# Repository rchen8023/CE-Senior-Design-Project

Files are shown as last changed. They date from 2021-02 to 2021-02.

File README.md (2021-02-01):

# CE-Senior-Design-Project

This project aims to create and design an independent IoT system allowing users to open and close their household vertical blinds with just a simple tap on their personal mobile phones or tablets. The project requires three parts involving the software, hardware, and mechanical developments. The software aspect involves a web application which allows the user to open or close the blinds as they wish. The web application communicates to the hardware unit via WiFi where the user data is received by the System On Chip (SoC), ESP8266. The ESP8266 can then send out PWM signals to the stepper motor which along with the mechanical design is able to physically move the window blinds. The web application is implemented using HTML and CSS styling uploaded to the ESP8266 web server. The ESP8266 is programmed using the Arduino IDE, and the mechanical design independently sketched and designed using Tinkercad

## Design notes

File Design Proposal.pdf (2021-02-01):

December 17, 2018

Smart Window Blinds
Aya Mistica & Rui Chen
Design Proposal

Aya Mistica & Rui Chen
1000 E University Ave
Laramie, WY 82071
amistic1@uwyo.edu | rchen2@uwyo.edu

December 6, 2018

Dr. Steven F. Barrett, Professor
University of Wyoming
College of Engineering and Applied Science 1000 E University Ave (EN 2085B) Laramie, WY 82071

Dear Dr. Barrett:

We, Aya Mistica and Rui Chen, both 4th year computer engineering students, are pleased to commence our senior design project for EE 4820. We would like to propose a project to create and design smart window blinds. This project features both software and hardware implementations, but we are excited to take on a project which will challenge our technical skills and knowledge to further mold us into competent and knowledgeable computer engineers. This cover letter will provide an overview of our proposed idea.

According to a survey conducted by Pew Research Center in January 2018, over 77% of American adults own or use a smartphone [1]. Due to the growth in smartphone users, wireless technologies have become more and more integrated into everyday objects and given rise to the Internet of Things (IoT). By 2025, it is estimated that there will be more than 55 billion IoT devices [2]. For these reasons, we propose to create and design wirelessly-controlled window blinds which will allow users to install the mechanism on pre-existing window blinds and control the blinds from their smartphone. Through the mobile app, users should be able to open, close, raise and lower the window blinds. This project aims to design an independent system allowing users to fully utilize their household blinds with just a tap on their screen.

We feel that this project will not only challenge us both technically and creatively, but will help us gain knowledge and understanding within the growing IoT field. Feel free to contact us with feedback and concerns through our school emails: amistic1@uwyo.edu or rchen2@uwyo.edu. We sincerely appreciate your time.

Kind regards,

Aya Mistica and Rui Chen

The Smart Window Blinds project aims to create a self-contained system which will

allow users to fully automate window blinds through their smartphone. The system consists of

two main components: an attachable module that provides motorized control to open, close, raise

and lower the window blinds and a smartphone app which will connect to the attachable module

over Wifi. For design and implementation purposes, the project is divided into three technical

aspects: software, hardware, and mechanical.

The objective of the software portion of the project is to create a mobile application

through Evothings Studio which will allow the user to communicate to our chosen

microcontroller, the ESP8266. Another goal for the smartphone app is to implement a

straightforward, clean interface for an easy-to-use experience. We would also like to add security

measures between the IoT device and mobile app to protect the privacy and data of our users.

On the hardware side, we will be using the ESP 8266 as the main “microcontroller”.

Using a standalone ESP 8266 will still give us full Wifi connectivity, efficient reception of data

from the mobile application as well as the capability of sending pulse width modulation signals

to the DC motor. The hardware will also include a 9V power supply, voltage regulators,

resistors, capacitors, wires and other circuitry components. Upon receiving input from the mobile

app, the ESP 8266 should output a corresponding PWM signal to the DC motor which will

physically move the window blinds. The PWM signal will be determined by the type of input

data received.

The mechanical system will be at the heart of physically moving the window blinds. It

will include a DC motor, gears, and other mechanical parts to raise and lower the system. More

research needs to be done on specific parts as well as how the mechanical system should move the blinds. Also, the system should be able to receive the PWM signal and move the window

blinds seamlessly, swiftly and efficiently.

Functional Block Diagram

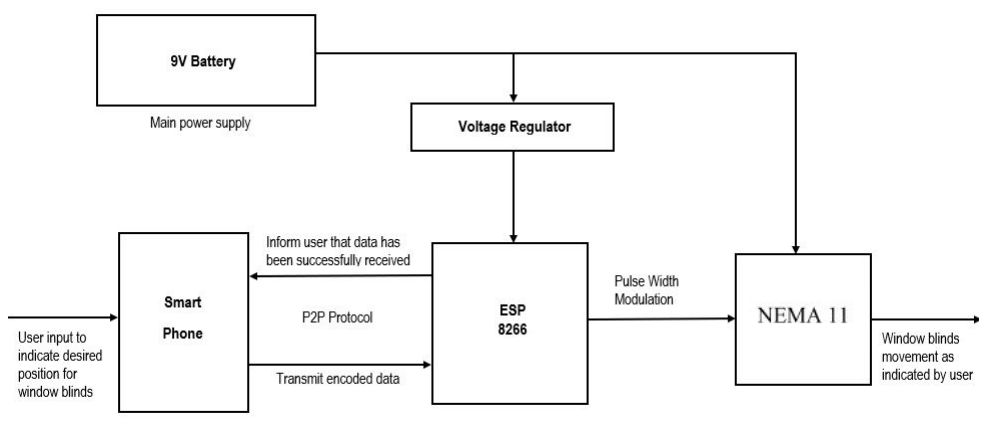
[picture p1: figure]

Figure 1. Smart Window Blinds

The block diagram in Figure 1 shows all the modules in the Smart Window Blinds project. Each

module will be described in detail based on specific inputs, outputs and functionalities.

Table 1: Smartphone Module

Module | Smartphone
Inputs | User interacts with mobile application to indicate desired position of window blinds. When ESP8266 receives encoded data, send success message back to mobile application to inform user.
Outputs | Transmit encoded data: using P2P Wifi Protocol, send user data to ESP 8266
Functionality | Exchange data wirelessly between Wifi module and user

Table 2: ESP 8266 Module

Module | ESP 8266
Inputs | Transmit encoded data: Using Wifi, decode received user input from smartphone
Outputs | When ESP8266 receives encoded data, send success message back to application to inform user. Send a pulse width modulation to DC motor determined by the decoded user data.
Functionality | Receive and decode user data to transmit appropriate pulse width modulation to DC motor.

Table 3: DC Motor

Module | NEMA 11
Inputs | Pulse width modulation from controller: moves the motor a specific angle based on the duty cycle of the signal. Power supply: 5V from L7805 voltage regulator
Outputs | Moves the window blinds as the user has requested
Functionality | Physically moves the window blinds based on user input

Table 4: Voltage Regulator

Module | Voltage Regulator
Inputs | Receives 9V from battery
Outputs | 3V-3.6V for the ESP 8266 Supply appropriate voltage for DC motor
Functionality | Supplies voltage to components in the system within safe operating conditions.

Current and Alternative Solutions

One of the problems we may face is unsuccessful communication between the ESP 8266

and the mobile application on the smartphone. Luckily, the ESP 8266 has extensive

documentation on setup, testing, and recommended usage. There are many suggestions and

proven tips by those who have done similar projects. We can find multitude of solutions once we

are in the debugging and testing stages of the project. Replacing the ESP 8266 is not an option

for us because then we would have to re-code and learn how to use a different wifi module.

Another problem we have is with the mechanical system that physically moves the

window blinds. This is probably the biggest obstacle for us since we are computer and electrical

engineering students. We have no experience with building mechanical systems and how to

make them work. We will have to find help within the mechanical engineering department to

gain perspective and insight on how to begin constructing the mechanical aspect of the project.

We also need to do more research on DC motors, torque, and other mechanical engineering

concepts.

Another possible issue is with the software development of the mobile application. We

may find that our chosen software development platform is not what we need or incompatible

with what we’re doing. There may be additional functionalities that we want that the integrated

development environment (IDE) lacks. An easy solution for this would be to research other IDEs

and finding one that is more fit for the project.

Table 5: Parts List

Item | Quantity | Cost | Total
ESP 8266-01 | 3 | $6.95 | $20.85
USB to TTL Adapter (CP2102) | 2 | $9.00 | $18.00
9V Battery | 1 (2-pack) | $7.80 | $7.80
Voltage Regulator | 4 | $0 ECE shop | $0
Miscellaneous Circuit Components (resistors, capacitors, wires, breadboard, etc.) | | $0 ECE shop | $0
L293D Motor Driver | 4 | $3.00 | $12.00
Evothings Studio Software Development | 1 | Free | $0
DC Motor | 5 | ~$7 | $35

3-D Printed Casing | 1 | ~$10 | $10
Vertical Blinds Set | 1 | ~$50
| | | $153.65

Table 5 shows the parts, quantity, and approximate cost for the Smart Window Blinds project.

Development costs are much higher due to ordering extra parts just in case. We also did not

include a smart phone since this is already privately owned by both members and adds no

additional expense.

Final Cost Analysis and Project Funding

The total cost for the Smart Window Blinds project is $73.65 which is well under-budget for the

provided $250 funding by the ECE department. No outside funding sources will be needed. This

cost estimate would be much lower if only the exact required quantities for each part are ordered.

One of the goals for the project is to design the system in the most reliable functionality but as

cost-effective as possible. With this cost estimate, the Smart Window Blinds can be priced

competitively in the IoT market.

Design/Construction

Software

To develop the software application, we have decided to use the platform, Evothings

Studio. With Evothings, we can easily create the front-end of the application using various web

technologies like HTML, CSS and Javascript. HTML will be used to create a structured layout

on the application; Javascript will handle all the functionality; and CSS will make the buttons and layout of the page appealing. All we need to do is download Evothings Workbench to our

laptop and the Evothings Viewer on our mobile devices.

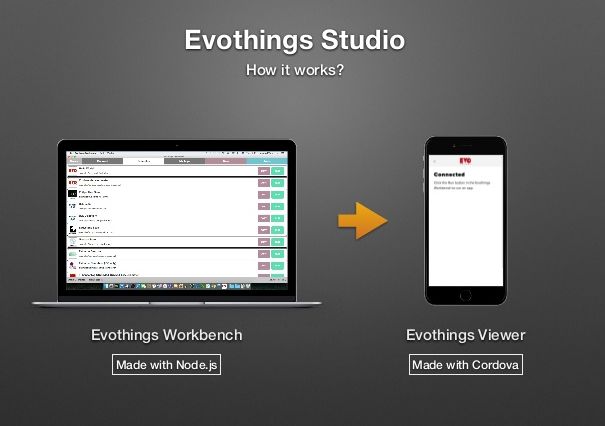
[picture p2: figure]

Figure 2. Evothings Workbench and Evothings Viewer.

Evothings Viewer is available for IOS and Android phones so we don’t need to create two

different codebases tailored to a specific operating system. The way it works is if a laptop and

mobile device is connected to the same Wifi network, the laptop and mobile device can be

connected via a specific “Connect Key”. Once connected, any new saved changes in the code

from the Evothings Workbench will auto-reload the Evothings Viewer on the mobile device and

reflect the changes in real-time as shown in Figure 2. Multiple devices will be able to run and

display our specific application as well. Currently, we plan on only supporting one range of

motion for our vertical blinds so we will only need to create an “Open/Close” button for the app.

Clicking this button on the app should open (if the blinds are closed) and close (if blinds are

open), the window blinds upon the user’s request. To test the connection between the mobile

application and the ESP 8266, we can first use an LED connected to the GPIO2 pin on the

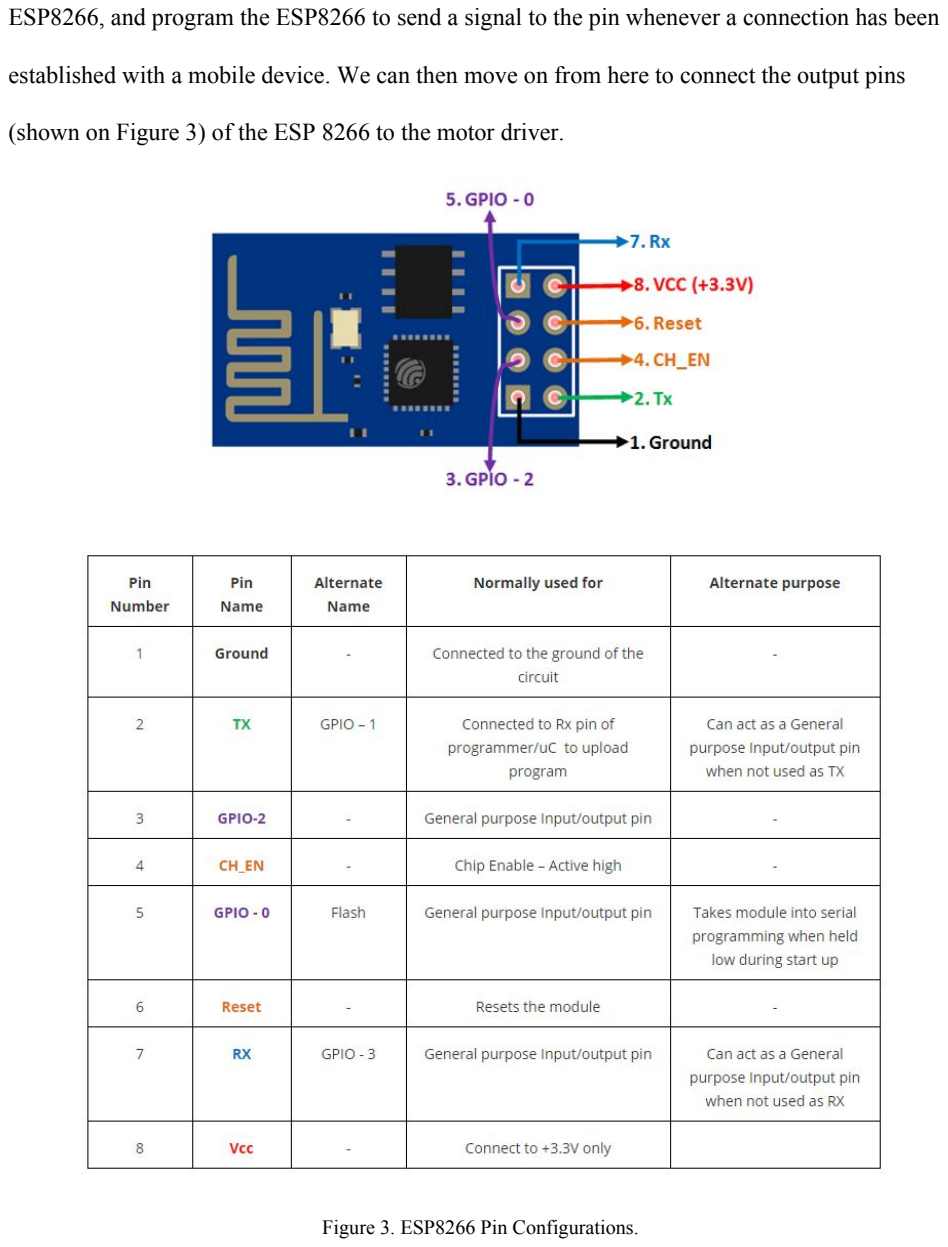
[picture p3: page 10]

ESP8266, and program the ESP8266 to send a signal to the pin whenever a connection has been

established with a mobile device. We can then move on from here to connect the output pins

(shown on Figure 3) of the ESP 8266 to the motor driver.

Figure 3. ESP8266 Pin Configurations.

Hardware

Once we obtain the ESP 8266 and FTDI Programmer, the first step is to program the

chip. We will program the ESP 8266 with NodeMCU which uses LUA script. Programming with

LUA using NodeMCU firmware is very similar to programming an Arduino. In addition, we

need to use ESPlorer program to create and upload LUA files into the ESP 8266. The first goal is

to establish communication between the Evothings application and ESP8266. We can confirm

this communication by connecting an LED to one of the pinouts of the ESP 8266, and when the

button is pressed on the Evothings mobile application, the LED should should light up. After

this, we can connect the ESP 8266 to send PWM signals to the motor driver which will drive the

DC motor. We can test the PWM signals first by connecting one of the pins to an oscilloscope

and when a button is pressed on the mobile application, we should be able to detect the PWM

signal on the oscilloscope.

Mechanical

Our mechanical design involves using the bipolar mini stepper motor, NEMA11. Its torque is 6

N-cm and it takes 200 steps/rev. Its voltage and current rating are 3.8 V and 0.67 A, respectively.

We chose this stepper motor on the premise of examining the motion involved in opening and

closing a vertical window blind. A manual window blind has a rotating wand which rotates a

1.8cm diameter knob at the top of the blind. To open and close, it takes 5 full turns of this knob.

Since we did not have a tool to measure the torque required to turn the knob, we are estimating

that a stepper motor with 6 N-cm torque is enough for our gear system. Connected to the stepper

motor is a gear system which will be attached to a metal rod. This metal rod should be inserted in the hole currently occupied by the rotating wand. With the gear system and rod, the motor should

be able to rotate the knob automatically. Right now we are not so much concerned about the

speed at which the window blind should open and close, but we need to make sure that the

stepper motor is capable of moving the gear system which will move the blinds. To be safe, we

may order a stepper motor which has a slightly greater torque, just in case 6 N-cm is not enough.

Once we are able to get it to work, we can worry about increasing the voltage delivered to the

motor to possibly increase its speed. Another concern is that a higher torque may require more

power from our 9V power supply, and we need to be careful with keeping the system

low-powered to prolong our battery life. Our motor driver for the stepper motor is the

DRV8833C. We will connect this to 3 I/O pins of the ESP 8266. One of the I/O pins will control

the sleep mode of the motor driver. The other two I/O pins are connected to output the PWM

signal to the motor driver. The pin that transmits the PWM signal will determine the direction

which the stepper motor will turn.

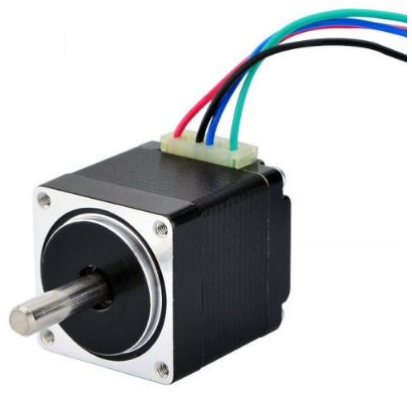
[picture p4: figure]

Figure 4. NEMA 11 Stepper Motor

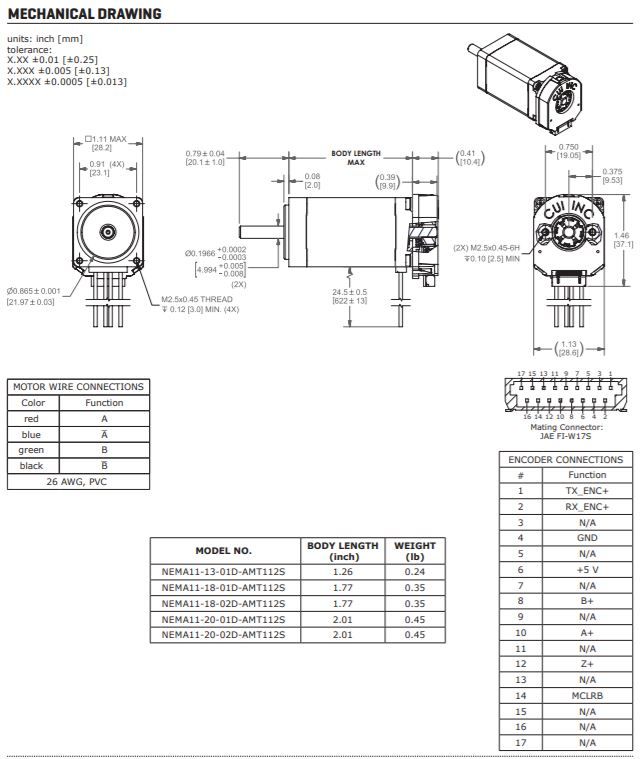
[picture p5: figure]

Figure 5. NEMA 11 Motor Data Sheet

Project Timeline With Specific Deadlines

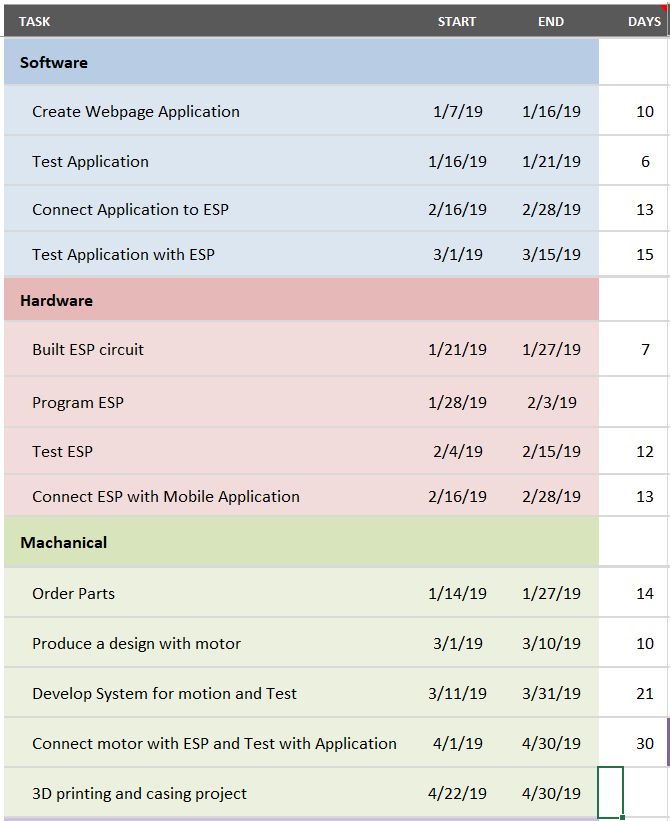
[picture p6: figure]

Schematic Diagram

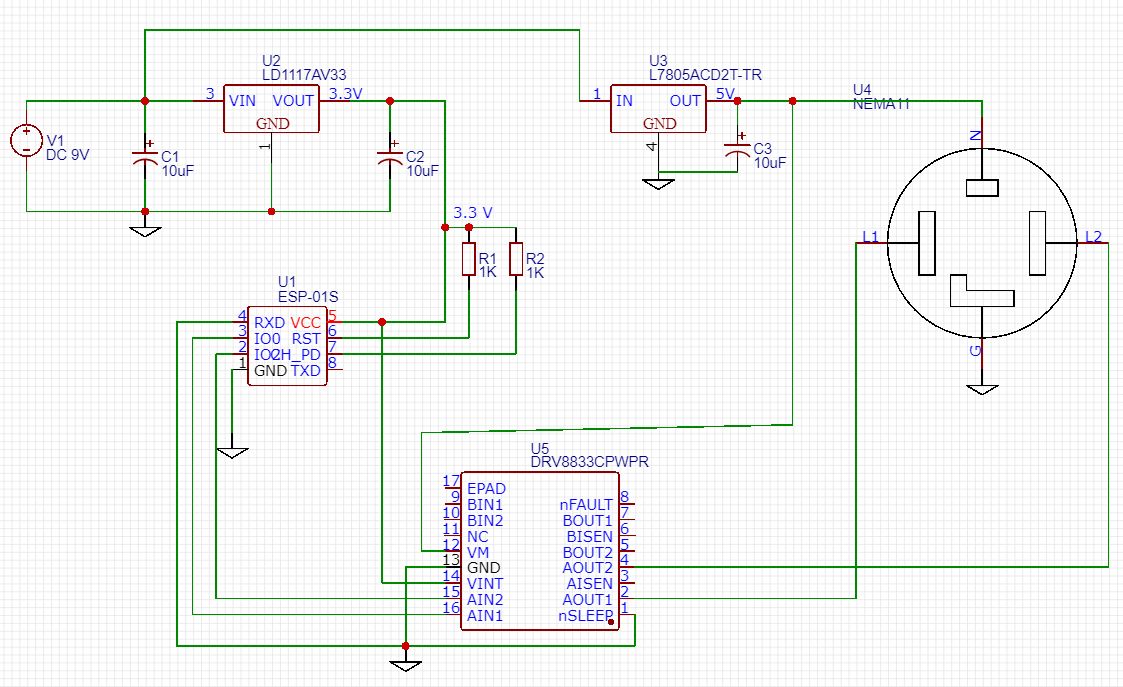
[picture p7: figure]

Figure 6. Smart Window Blinds Schematic Diagram.

For our schematic, we are using a 9V DC power supply. 9V is fed into LD1117 and steps

down to 3.3 V to power our ESP 8266. It is also an input to L7805A which will output 5V for

our stepper motor and motor driver. Our motor driver is the DRV8833C and our stepper motor is

the NEMA 11. L1 and L2 are connected to AOUT1 and AOUT2 of our motor driver which will

control when the stepper motor moves and in what direction. AIN1 and AIN2 will receive the

PWM signal from the IO0 and IO2 pins of the ESP 8266 and this will control the direction in

which the stepper motor moves. RXD of the ESP 8266 can be used as a general pin when not in

programming mode, and this will be connected to nSleep of the motor driver. nSleep will put the motor driver in sleep mode when it's set to 0, and enables the motor driver when set to 1. We

have the 10uF capacitors at the input and output of the voltage regulators to keep the circuit

stable. In addition, we have RST (Reset) and CH_PD (chip enable) set to HIGH to make sure the

ESP 8266 does not reset when it’s not suppose to as well as to enable to the Wifi module.

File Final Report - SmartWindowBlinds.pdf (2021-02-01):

Smart Window Blinds
EE4830 Senior Design II
Aya Mistica & Rui Chen
Steven F. Barrett, Ph.D., P.E. Electrical and Computer Engineering Department College of Engineering
University of Wyoming
Laramie, WY 82071
amistic1@uwyo.edu & rchen2@uwyo.edu

Abstract
According to a survey conducted by Pew Research Center in January 2018, over 77% of American adults own or use a smartphone [1]. Due to the growth in smartphone users, wireless technologies have become more and more integrated into everyday objects and given rise to the Internet of Things (IoT) [2]. By 2025, it is estimated that there will be more than 55 billion IoT devices.
This project aims to create and design an independent IoT system allowing users to open and close their household vertical blinds with just a simple tap on their personal mobile phones or tablets. The project requires three parts involving the software, hardware, and mechanical developments. The software aspect involves a web application which allows the user to open or close the blinds as they wish. The web application communicates to the hardware unit via WiFi where the user data is received by the System On Chip (SoC), ESP8266. The ESP8266 can then send out PWM signals to the stepper motor which along with the mechanical design is able to physically move the window blinds. The web application is implemented using HTML and CSS styling uploaded to the ESP8266 web server. The ESP8266 is programmed using the Arduino IDE, and the mechanical design independently sketched and designed using Tinkercad.

Keywords
Smart Window Blinds, Wireless Home System, Internet of Things, IoT, Wireless Window Blinds, Smart Home System, ESP8266

Overview
Project Scope
The Smart Window Blinds project aims to create a self-contained system which will allow users full automated control of their household vertical blinds through a smartphone or tablet device. The system consists of two main components: a compact attachable unit that provides motorized control to open and close the window blinds as well as a web application which will connect to the attachable unit over Wifi. For design and implementation purposes, the project is divided into three technical parts: software, hardware, and mechanical.
The objective of the software portion of the project is to create a simple web application which will allow the user to communicate to our WiFi module, the ESP8266. It should allow the user to choose what type movement they desire for the vertical blinds and successfully send the user data to the ESP8266. Upon choosing an action, the web application should also reflect what button was previously pressed and indicate a status for the blinds.
The hardware unit consists of the ESP8266, stepper motor driver and other electrical components to ensure proper operation and interfacing between the mobile device and stepper motor. Within the hardware unit, the ESP8266 needs connect to the mobile device via WiFi and properly decode the transmitted user data. Based on the user data, the ESP8266 should output a PWM signal to the proper output pins which are connected to the stepper motor driver. Upon sending control signals to the stepper motor driver, the stepper motor should activate.
The mechanical system will be at the heart of physically moving the window blinds. It will include a stepper motor, a block attachment between the stepper motor and blinds as well as a twist bar. The block attachment will allow the stepper motor to be mounted on the side of the window blinds while the twist bar models a small rod which fits the stepper motor on one end and the turning knob of the window blinds on the other.

Project Goals
For the software portion of our project, our goal is to implement a straightforward, easy-to-use and simple web application. There should be two buttons that users can choose from to move the window blinds in their desired position. Upon pressing the button, a status should be displayed on the web application indicating that the user data was successfully sent. The purpose of displaying a status when a button was pressed, besides for testing purposes, is also to communicate to the user that their action was successful.
Our project also aims to fulfill the needs of consumers to have a reliable, easy-to-use, minimum upkeep but affordable product for their smart home goals. Compared to other wireless window blinds, our design will offer the same functionalities, but at a more cost-effective price. With the installable module, our users will not need to replace their current window blinds, unlike other products that require their customers to purchase a whole new set of blinds. The attachable module will be designed for quick and easy installations, keeping in mind that in most cases, buyers have multiple blinds in their homes. The product will be sleek and compact in design, well-hidden to preserve the aesthetics of the home or business. In addition, users have their smartphone or tablet device to automatically control their blinds unlike using a remote control which can be easily lost or damaged. We also aim for our IoT system to be low-maintenance, only requiring a 9V battery supply. The battery should last at least 6 months so that the users will not be inconvenienced by frequent replacement of batteries.

Background
The Smart Window Blinds systems falls under the category of Internet of Things devices. Internet of Things can be summarized as integrating common objects like mobile phones, home appliances, furniture, window blinds, etc. with sensors or other electrical components so that these objects can communicate with each other [3]. Our project implements the communication between a mere vertical window blinds and a mobile device. The impact of IoT devices is great especially for individuals in their everyday life. It allows for the creation of “smart” objects within the home and in industry.
ESP8266 [4] is a self-contained SOC with integrated TCP/IP protocol stack that can give any microcontroller access to our WIFI network. It is capable of either hosting an application or offloading all WIFI networking functions from another application processor. ESP8266 does not require for high voltage, the voltage supply for VCC is 3.3V. The standby current is around 0.9 uA and the running current in average is 80mA. It contains two input and output pins so that it can send out the signals when it communicate the software module. The ESP8266 module is an extremely cost effective board with a huge, and ever growing, community.

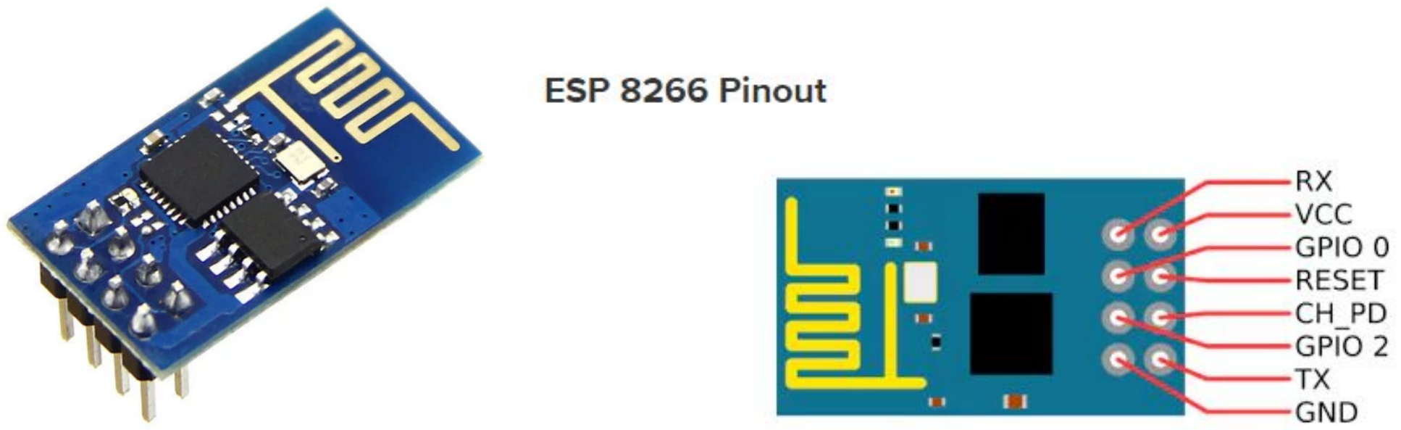
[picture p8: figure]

Figure 1. ESP8266 WIFI Module. Technical Project Description
I. Functional Description
The block diagram in Figure 2 shows all the modules in the Smart Window Blinds project. The inputs of the system is the desired window blinds action input data from user to web application. The web application will develop the P2P WIFI protocol communication with WIFI module, the ESP8266. Then the ESP8266 can send out PWM signals to the stepper motor which will physically move the window blinds. Also the system includes a 9V Battery supply, voltage regulators and other circuitry components. The voltage regulators will reduce the 9V to 3.3V for ESP8266 and 5V for motor driver. The Table 1 - 3 below described in detail based on specific inputs, outputs and functionalities for each module.

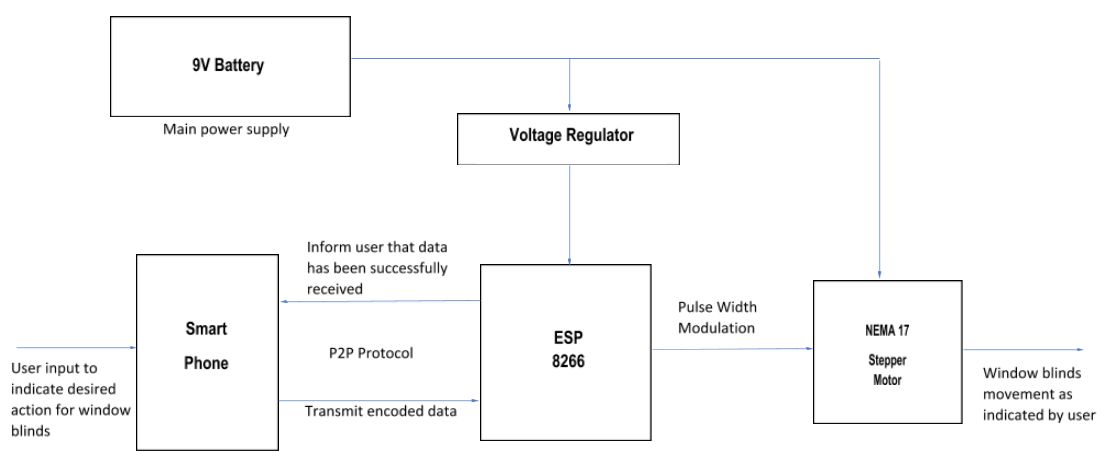
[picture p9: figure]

Figure 2. Block Diagram Smart Window Blinds

Table 1. Smartphone Module
Module | Smartphone
Inputs | User interacts with mobile application to indicate desired position of window blinds. When ESP8266 receives encoded data, send success message back to mobile application to inform user.
Outputs | Transmit encoded data: using P2P Wifi Protocol, send user data to ESP 8266
Functionality | Exchange data wirelessly between Wifi module and user

Table 2. ESP8266 Module
Module | ESP8266
Inputs | Transmit encoded data: Using Wifi, decode received user input from smartphone

| Power supply: 3.3V from voltage regulator
Outputs | When ESP8266 receives encoded data, send success message back to application to inform user. Send a pulse width modulation to DC motor determined by the decoded user data.
Functionality | Receive and decode user data to transmit appropriate pulse width modulation to DC motor.

Table 3. Stepper Motor
Module | NEMA 17
Inputs | Pulse width modulation from controller: moves the motor a specific angle based on the duty cycle of the signal. Power supply: 5V from voltage regulator
Outputs | Moves the window blinds as the user has requested
Functionality | Physically moves the window blinds based on user input
II. | Software Module
To implement our web application, we used HTML and CSS styling. Both of these together allowed us to display our project name as a header so that users will know that they are in the correct webpage. In addition, we created two buttons in the web application (shown in Figure 3): left and right. These two buttons can be pressed to indicate the desired direction for the vertical window blinds to move. After pressing a button, the page reloads and displays the web application again but with a status as shown in Figure 4.
Since the ESP8266 can be used as a web server, we opted to put all of our HTML and CSS code in the ESP8266’s web server. Not only was this free, but provided an easier way for us to manage the web application and ESP8266 communication. We found extensive tutorials of how to implement this in [5]. Using this resource, we learned to put our HTML and CSS code into header files to be used in the Arduino code which is then uploaded onto the ESP8266. Our handleOpen() and handleClose() functions call the ESP8266 server to send our HTML and CSS code so that the web application can be displayed to client.

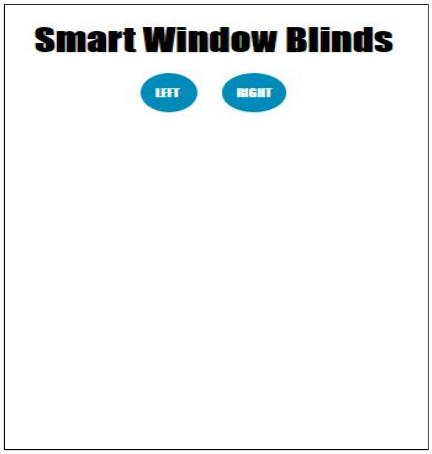
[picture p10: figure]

Figure 3. Smart Window Blinds Web Application

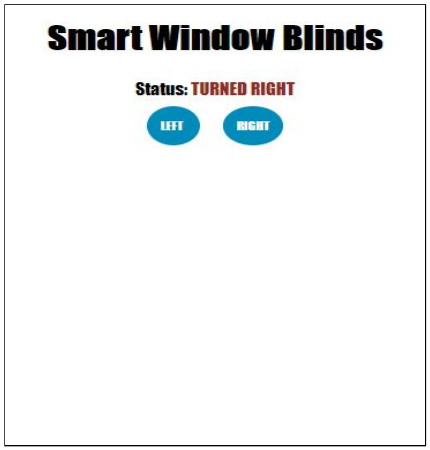
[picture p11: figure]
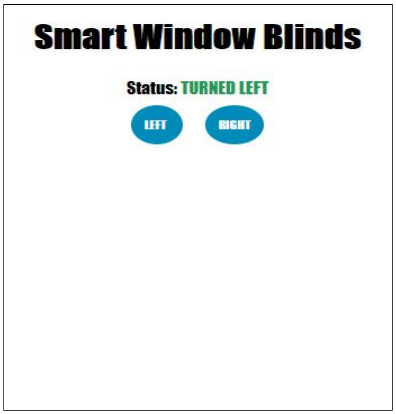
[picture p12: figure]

Figure 4. Web App with Status In order to access the web application, we used the WifiManager library [6] from Github and included this in our Arduino libraries. The purpose of this was to prevent needing to hardcode WiFi SSID and password to the Arduino code when network credentials change. WiFi Manager provided a user interface to enter WiFi information every time the ESP8266 is powered on, or if it does not see any saved WiFi SSID and password (shown in Figure 5).

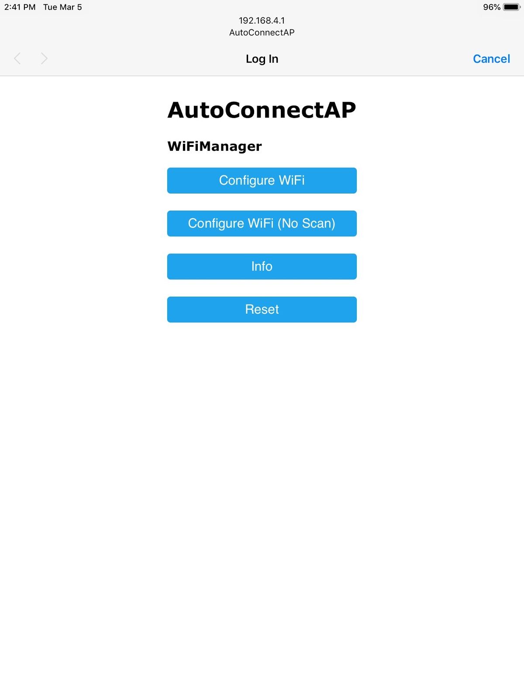
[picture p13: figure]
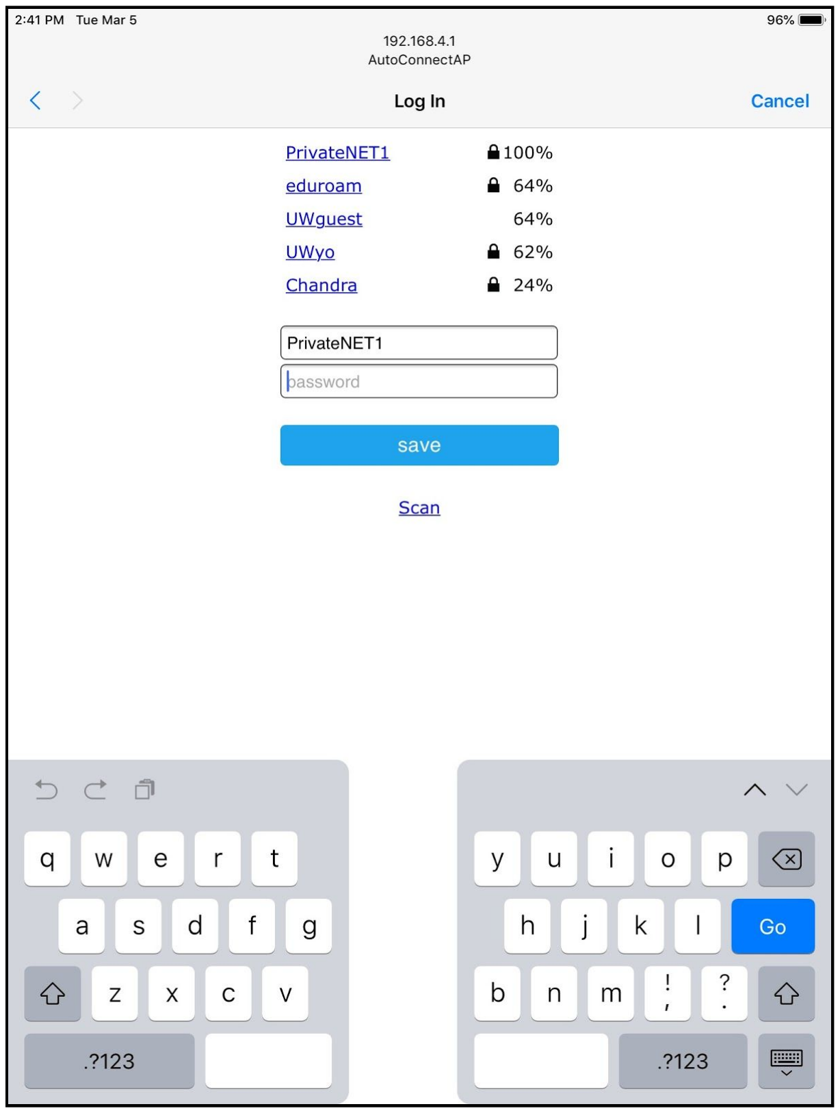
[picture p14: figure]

Figure 5. WiFi Manager
Pressing the “Configure WiFi” under AutoConnectAP would then show all of the available networks that can be connected to the ESP8266. Once the mobile device and ESP8266 are in the same network, the IP address of the ESP8266 can be entered into a browser which will direct the user to the web application. Initially, we knew the IP address of the ESP8266 from the Serial Monitor of the Arduino software. Later on, we found out that it is displayed on our laptop when we use it as a mobile hotspot.

III. Hardware Module
On the hardware side, we used the ESP8266 as a microcontroller unit. Using the
ESP8266 by itself allowed us access to full WiFi connectivity, efficient reception of data from the mobile application as well as the capability of sending signals to our stepper motor driver, the DRV8834 motor driver carrier [7]. When a button is pressed on the web application, the ESP8266 receives this data and acts accordingly. We have defined two functions when a button is pressed in the web application: handleOpen() and handleClose(). The names reflect the initial names of the buttons when our buttons used to be “Open” and “Close”. Now, the buttons are named “Left” and “Right” to better convey which direction the blinds will move. If the “Left” or “Right” button is pressed, the ESP8266 sends a HIGH signal to the SLP pin of the motor driver to enable it. An analogWrite() is then sent to the GPIO0 of the ESP8266 to send a PWM signal with 50% duty cycle. This signal is then transmitted to the motor driver STEP input pin. This PWM signal corresponds to how fast the stepper motor should turn. Another signal is also sent from the ESP8266 which is just a simple HIGH or LOW signal to the DIR pin of the stepper motor driver. This signal indicates which direction the stepper motor will turn, whether clockwise or counterclockwise. After a 2.2 second software delay, the SLP pin is turned back to

LOW and the ESP8266 stops sending PWM signals to indicate that the stepper motor should now be stationary. Within our hardware module are various voltage regulators, a 3.3 V [8] and 5V [9] regulator. The 3.3V is provided for the ESP8266 and the 5V for the stepper motor driver. In addition, we have added some bypass capacitors to dampen any noise in the signals. These components can all be seen on our PCB board in Figure 6.

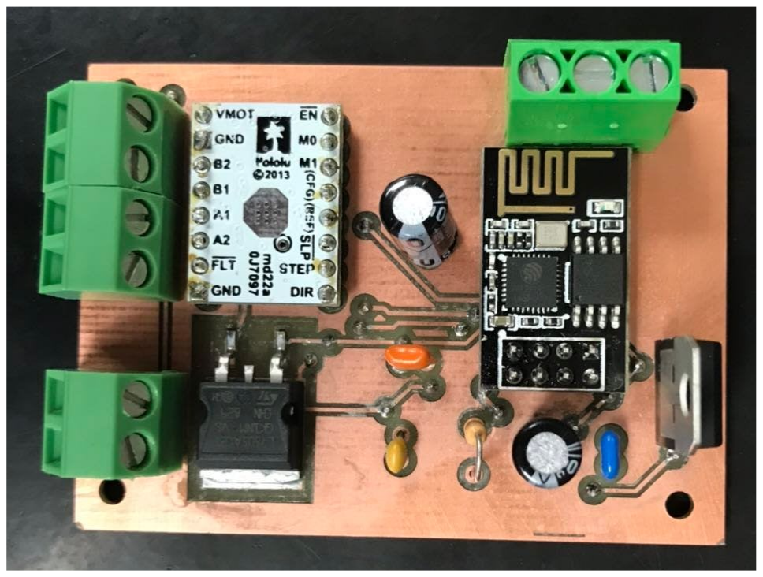
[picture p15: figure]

Figure 6. Hardware PCB Board IV. Mechanical Module
For the mechanical module, we used a bipolar stepper motor, NEMA 17. It holds a high torque with 13 N-cm and takes 200 steps/rev. It draws 1A current per phase, which allows the stepper motor be able to drive it with the output current up to 2A per coil in 5V voltage supply. We chose this stepper motor on the premise of examining the motion involved in opening and closing a vertical window blind. A manual window blind has a rotation wand which rotates a 1.8cm diameter knob at the top of the blind. To open and close, it takes 5 full turns of this knob. Since we did not have a tool to measure the torque, we first estimated that a stepper motor with 6 N-cm torque is enough for our mechanical system. However, when we test our system with this stepper motor, it is not able to move the window blinds, then we changed to use the stepper motor with higher torque. This stepper motor has 4 input wires, we connected those 4 input to the 4 output pin on DRV8834 stepper motor driver carrier in a particular order, so that the stepper motor can send out the PWM signal and the current to drive the stepper motor to physically move the window blinds without vibrations.

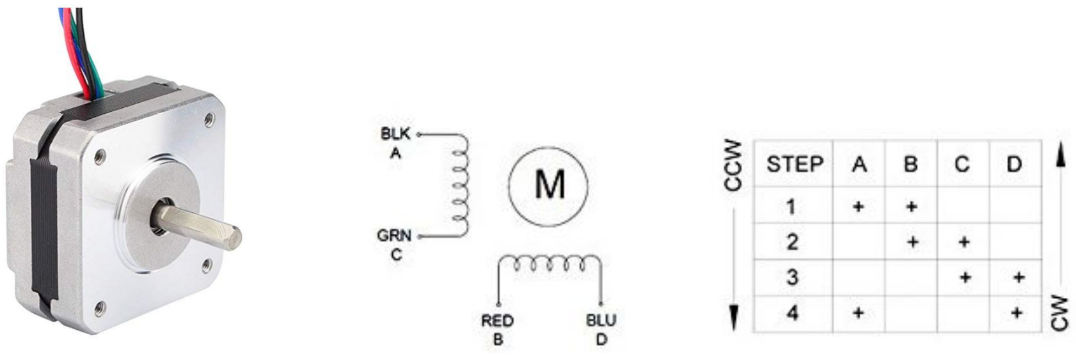
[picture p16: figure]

Figure 7. NEMA 17 bipolar stepper motor

Our Mechanical design consists two part: Twist Bar and Motor-Blind Attachment, shown in Figure 8 and Figure 9. The twist bar a small rotating fixture with different shapes on each side. This part will attach the metal rod of the stepper motor and the window blind. Then the window blind is able to move as the motor is turned on. The motor-blind attachment is a square block that attaches to stepper motor and window blinds, so that the stepper motor can be mounted on the side of window blinds. All the parts are designed by using Tinkercad and 3D printed by University of Wyoming IT Department.

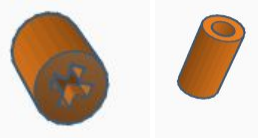
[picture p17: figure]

Figure 8. Twist Bar

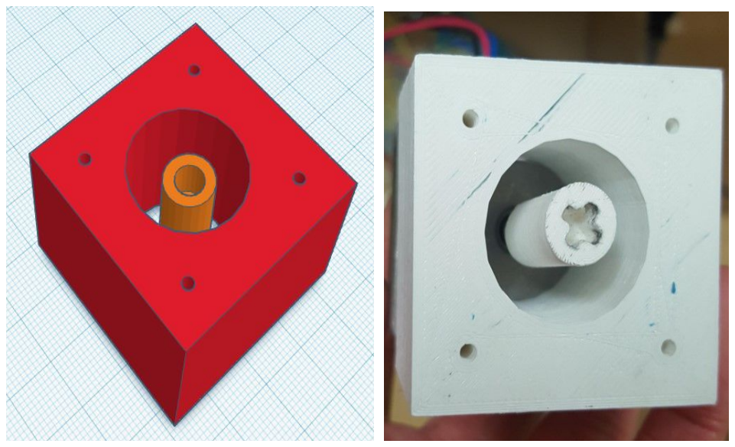
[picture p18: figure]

Figure 9. Motor-Blind Attachment

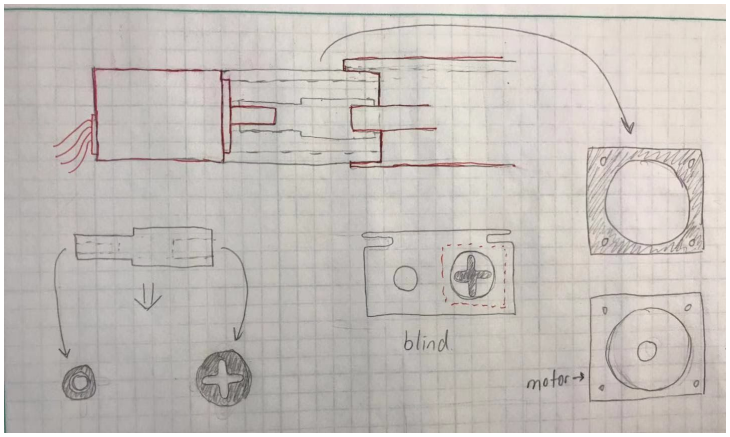
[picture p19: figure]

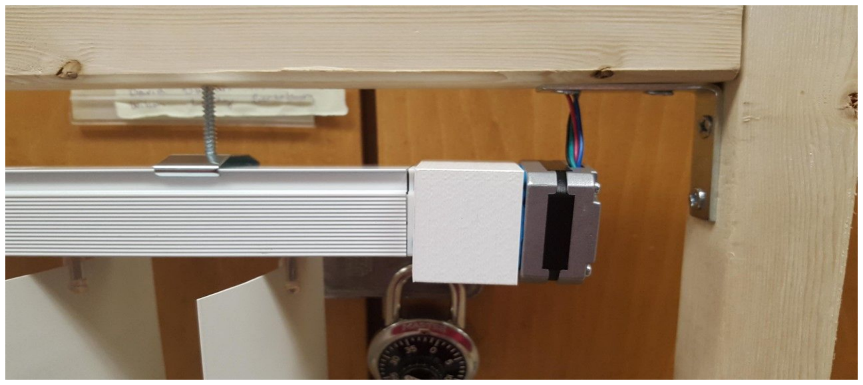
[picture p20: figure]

Figure 10. Mechanical Design Testing
I. Software Testing
Initial testing for the web application heavily involved the Serial Monitor of the Arduino. We added print statements in certain functions within our Arduino code to make sure that when a button on the web application is pressed, we would be able to see that these functions were properly executing. In addition to this, if these print statements (shown in Figure 11) are displayed on the Serial Monitor, we can safely assume that the web application and the ESP8266 have established communication with each other. In addition, we also tested the WiFi Manager by entering the current network credentials we were using and seeing that the ESP8266 successfully connects to it which is also confirmed via the Serial Monitor.
One thing to note during this testing progress was when we found out that the ESP8266 cannot be connected to WiFi transmitting in the 5GHz frequency band. It can only connect to the 2.4GHz frequency band. We discovered this because when we would test our system in the lab, sometimes our mobile hotspot would switch frequency bands. When this happens, and the WiFi network is in the 5GHz frequency band, the WiFi Manager--which generally shows up in the Network list of the mobile device--is not listed. Once we switch our WiFi network back to 2.4GHz communication band, the WiFi Manager can be found again.

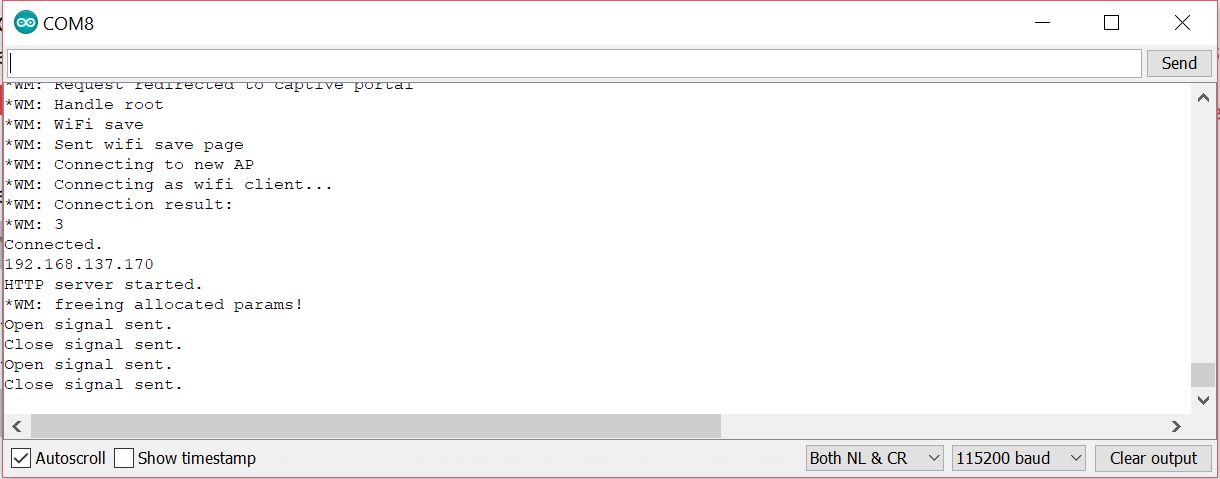
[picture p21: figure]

Figure 11. Serial Monitor Print Statements for Testing

II. Hardware Testing
Our hardware module was tested on a breadboard with a 9V power supply. We first started with connecting the output of voltage regulators to multimeter to check if the voltage was reduced from 9V to 3.3V and 5V. We secondly tested if the programmed WIFI module, ESP8266, is able to communicate with web application on the breadboard. During testing, the output pin of the ESP8266 was connected to the oscilloscope. When we press the open or close button on web application, the LED of ESP8266 turned on and an output signal was shown on the oscilloscope, which means the programmed ESP8266 is communicating with our web application. Then we tested the hardware module with our stepper motor driver. However, since we started with a motor driver chip without the heat sink and adapter, so the chip was broken by high temperature. Then we changed to use DRV8834 motor driver carrier with heat sink and adapter. We connected the input and output pings of motor driver carrier to the oscilloscope to check if there is any PWM signals go into and out from the motor driver carrier. We set 50% PWM signal since it is about the average speed of signal sending. The figure 13 shows the output signal of the motor driver carrier with 50% PWM.

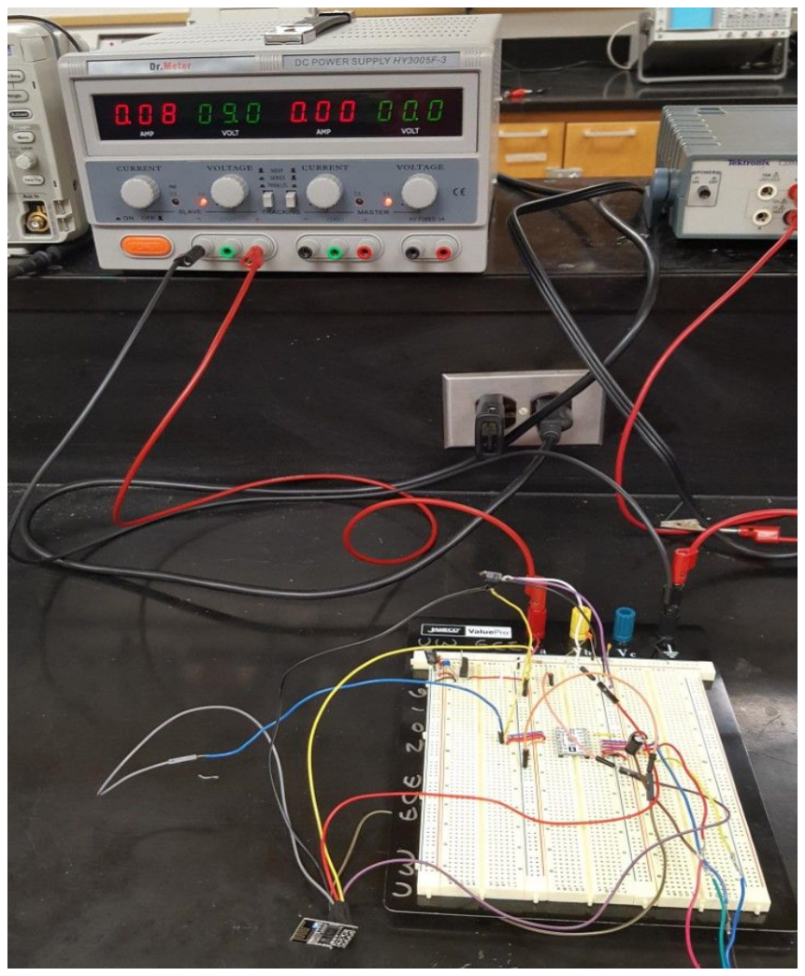
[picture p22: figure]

Figure 12. Hardware Testing.

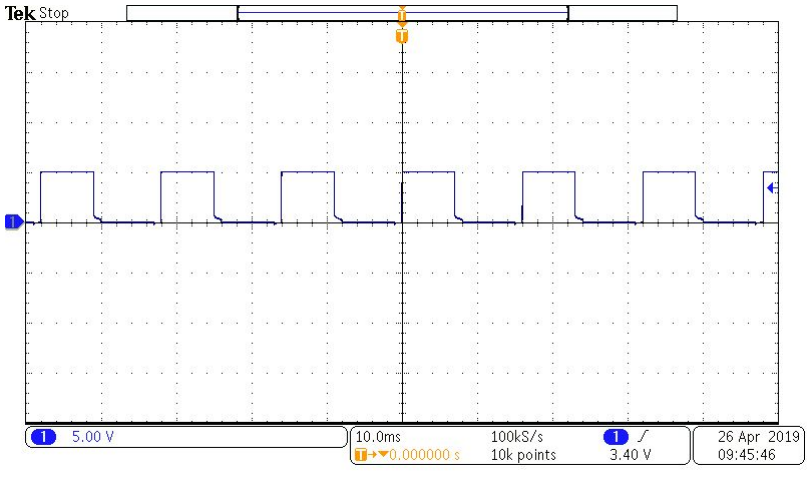
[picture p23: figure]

Figure 13. 50% PWM output signal of DRV8834 motor driver carrier
III. Overall Testing
The entire system was tested by connect the NEMA 17 stepper motor to the hardware system. At the initial testing, there were some vibrations occurred, and then we realized that it is because we randomly connected the four wires of stepper motor with the four output pin of the stepper motor driver carrier. To fix the vibrations, we followed the wiring diagram of DRV8834 stepper motor driver carrier (shown in Figure 14.) to rewire the stepper motor to the motor driver. We then mounted the stepper motor to the window blinds for the final testing. To prevent overturning the window blinds in one direction, we tested different time delay to keep the motor on by change the delay in the code. As result, we figured out that 2.2 seconds delay is the best time before turning off control signals and putting motor driver back to sleep mode. So that there is no overturning when the window blinds is turned on and off in one direction.

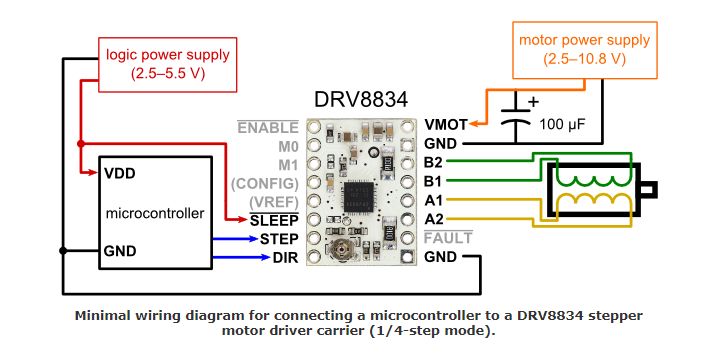
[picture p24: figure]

Figure 14. Wiring Diagram for DRV8834


Figure 15. Overall Testing Packaging
Our packaging contains a battery compartment and rocket switch placement. The battery compartment will be attached on the top of the packaging box, so that there is enough space underneath the battery compartment that allow us to mount the PCB board under the battery compartment. A 9V battery case will be place in the battery compartment allowing the users to replace the 9V battery if needed. The wires of the battery case will be connected to the PCB board by passing through the hole in the back of the battery compartment. The stepper motor will be mounted on the back side of the packaging box. All the wires of the stepper motor will pass through the hole in the back of the packaging box to connect to the motor driver on the PCB board. After we mounted all the components, a lid will be screwed on the packaging box. All parts are designed using Tinkercad and 3D printed by University of Wyoming IT Department.


Figure 16. 9V battery case.


Figure 17. Packaging
Other Consideration
I. Project Cost
Table 4. Project Costs
Item | Quantity | Cost | Total
ESP 8266-01 | 3 | $6.95 | $20.85
USB to TTL Adapter (CP2102) | 2 | $9.00 | $18.00
9V Battery | 1 (2-pack) | $7.80 | $7.80
Voltage Regulator (3.3V) | 3 | $0.54 | $1.62
Voltage Regulator (5V) | 3 | $0.78 | $2.34
DRV8834 Motor Driver Carrier | 2 | $5.95 | $11.90
NEMA 17 Stepper Motor | 2 | $13.5 | $27
3-D Printed Casing & Mechanical Parts | 1 | $21 | $21
Vertical Blinds Set | 1 | $27.51 | $27.51

$138.02

II. Other consideration
Ethical
Our design appropriately follows the guidelines of the IEEE Code of Ethics. It strictly follows section 1 under the IEEE Code of Ethics “to hold paramount the safety, health, and welfare of the public, to strive to comply with ethical design and sustainable development practices …” as discussed later under Environmental/Sustainability, Health and Safety. If we find any other possible dangers to our design, we strive to promptly disclose this to the public so that they are fully aware. In addition, we also aim to improve our design by accepting feedback and criticisms from others.

Social and Political
A political issue that may arise from creating and manufacturing our product is security attacks on the supply chain. For example, imported components that we use to create our system may have been tampered with for malicious purposes. These components may have the quiet capability to collect and track data as the components travel to the country and used in residential homes.
Another political issue we may face in the future if we decided to mass produce this design is deciding whether to have manufacturing facilities within the US or in foreign countries. If the latter, we must be able to provide fair wage and working conditions to workers in factories and manufacturing facilities within those countries.
A social issue from using the Smart Window Blinds is that it is an internet-connected device. It belongs under IoT devices which in the past--and still some today--garnered a reputation for having low-security. The general public will be concerned that our system does a constant and effective job of protecting their data and we need to ensure that cybersecurity becomes a priority in further developments of our design.

Health & Safety
To consider the health and safety of our users, we first need to consider security challenges involving our system as well as certain safety conditions within a typical household. First, our system may be vulnerable to cyber attacks where the data of our users can easily fall into the wrong hands. We need to implement a more secure system to ensure that our users and their information is protected. This may be by using secure communication protocols between the ESP8266 web server and the web application so that all packet headers and data are encrypted. In addition, we also need to consider when our system may cause harm within the home. These situations may be when children are able to reach the attachable unit and use it for unintended purposes.

Environmental/Sustainability
Our project affects the environment by using its limited natural resources--from the electrical components we used to our packaging--in order to build our system. With this in mind, we want to provide 9V rechargeable batteries with the Smart Window Blinds system to reduce batteries (which contain toxic chemicals) from going back out into the environment once they are maxed out. People who use our system will not need repeatedly purchase batteries, but can simply recharge the ones they already have and reuse. In addition to this, we can reduce waste even more by using lesser amounts for our packaging.

Aesthetics
One of our goals in our design is to ensure that it does not disrupt the overall ambience of the room, regardless of where it is placed. We wanted to make the system compact in size and can be well-hidden if need be. In addition, we chose the color white for our packaging since it is a very neutral color and easily blends with the surroundings.

Manufacturability
The Smart Window Blinds system has been designed to optimize manufacturing functions like assuring best cost to quality, fabrication, testing, and other manufacturability factors. Our design uses minimum and low-cost materials so that it is easier for mass production. Our design is compact in size, as seen on Figure 6 of our PCB board, and can be easily repaired if malfunctions occur. Testing our design also does not take a long time because problems that occur during the process can be easily pinpointed to a specific module in the project: software, hardware or mechanical.

Lessons Learned
Throughout the design process, we have learned many things. One of the biggest is to compartmentalize tasks and certain parts of our project. Looking at the project in its entirety seems overwhelming, but when we were able to segment each part into software, hardware and mechanical modules, we were able to visualize and comprehend more clearly specific tasks we needed to do. We’ve come to realize that in engineering and in doing large-scale projects, it’s vital to compartmentalize parts of the project. In this way, we can focus on one thing at a time whether the software part or the mechanical portion of the project. Another critical thing we learned is how important the online community is to troubleshoot and design certain aspects of our system. In particular, this applied to our software module integrating with our ESP8266. We are glad that we chose to use the ESP8266 for this project because there were so many tutorials and helpful documents online that allowed us to successfully implement our design. We never would have found out about the WiFi Manager library or using ESP8266 as a web server if it weren’t for hobbyists and passionate individuals who have extensively documented their experience with the ESP8266. For the future, we know to opt for components, programming practices, softwares and other technological factors in the project process that have extensive documentation and resources available. Another skill that we picked up is strictly following schedules.

Doing this project has been good practice for us in maintaining and following our schedule for the past 3 months. Dr. Barrett was totally right when he said that we should not stress out about all the parts of the project and what we needed to do but just focus on the current thing on our schedule. We know, for certain, that in the future, when we handle other engineering projects that following and maintaining an appropriate project deadline and schedule will be paramount.

References
[1] “Mobile Fact Sheet.” Pew Research Center Internet & Technology, Pew Research Center,
5 Feb. 2018, www.pewinternet.org/fact-sheet/mobile/.
[2] Newman, Peter. “IoT Report: How Internet of Things Technology Growth Is Reaching Mainstream Companies and Consumers.” Business Insider, 27 July 2018, www.businessinsider.com/internet-of-things-report.
[3] Gubbi, Jayavardhana, et al. “Internet of Things (IoT): A Vision, Architectural Elements, and Future Directions.” Future Generation Computer Systems, vol. 29, no. 7, Sept. 2013, pp. 1645–1660.
[4] Sparkfun. ESP8266 Module. Datasheet: https://cdn.sparkfun.com/datasheets/Wireless/WiFi/ESP8266ModuleV1.pdf
[5] tzapu. WifiManager: ESP8266 Wifi Connection Manager. 2018. Github repository: https://github.com/tzapu/WiFiManager
[6] Pieter, P. ESP8266 First Web Server. 2017. Github page: https://tttapa.github.io/ESP8266/Chap10%20-%20Simple%20Web%20Server.html
[7] Texas Instruments. DRV8834 Dual-Bridge Stepper or DC Motor Driver. Datasheet: https://www.ti.com/lit/ds/symlink/drv8834.pdf
[8] Mouser. LD1117AV33 Datasheet. 3.3V voltage regulator: https://www.mouser.com/datasheet/2/389/ld1117a-974076.pdf
[9] Mouser. L7805ACD2T-TR Datasheet. 5V voltage regulator: https://www.mouser.com/datasheet/2/389/l78-974043.pdf

Appendices
Appendix I. Schedule
Table 5. Project Schedule


Appendix II. Parts Lists

Figure 18. Part lists
Appendix III. PCB Board & Schematic

Figure 19. PCB Board


Figure 20. Schematic

Appendix IV. Arduino Code

#include <ESP8266WiFi.h>

#include <WiFiManager.h>

#include <WiFiClient.h>

#include <ESP8266WebServer.h> #import "index.h"

#import "open.h"

#import "close.h"

const int dirPin = 2; | //GPIO2
const int stepPin = 0; | //GPIO0
const int sleepPin = 3; | //Using RXD as GPIO during normal mode operation
WiFiServer server(1337);
ESP8266WebServer ESPserver(80);
//String header;
WiFiClient client = server.available();

void printWiFiStatus();
void handleRoot();
void handleOpen();
void handleClose();

void setup(void) {
Serial.begin(115200);

WiFi.disconnect();
Serial.println("Wifi Credentials Reset");

WiFiManager wifiManager;
wifiManager.autoConnect("AutoConnectAP"); Serial.println("Connected.");

pinMode(dirPin, OUTPUT);
pinMode(stepPin, OUTPUT);
pinMode(sleepPin, OUTPUT);

Serial.println(WiFi.localIP());

// Start TCP server.
server.begin();

ESPserver.on("/", handleRoot); //Which routine to handle at root location ESPserver.on("/open", handleOpen);
ESPserver.on("/close", handleClose);

ESPserver.begin();
Serial.println("HTTP server started.");
}

void loop(void) {
// Check if module is still connected to WiFi. if (WiFi.status() != WL_CONNECTED) { while (WiFi.status() != WL_CONNECTED) { delay(500);
}
// Print the new IP to Serial.
printWiFiStatus();
}

ESPserver.handleClient();
WiFiClient client = server.available();

if (client) {
Serial.println("Client connected.");

if (!client.connected()) { Serial.println("Client disconnected."); client.stop();
}
}
}

void printWiFiStatus() {
Serial.println("");
Serial.print("Connected to ");

Serial.print("IP address: "); Serial.println(WiFi.localIP());
}

void handleRoot() {
String htmlStr = main_page; //define html file in string ESPserver.send(200, "text/html", htmlStr);

}

void handleOpen() {
String htmlStr = open_page; //define html file in string
ESPserver.send(200, "text/html", htmlStr);
digitalWrite(sleepPin, HIGH); //enables motor driver, turns off sleep mode digitalWrite(dirPin,HIGH);
analogWrite(stepPin, 127); //set PWM to 80% duty cycle for now, IO0 Serial.println("Open signal sent.");
delay(2200);
analogWrite(stepPin,0);
digitalWrite(sleepPin,LOW);
}

void handleClose() {
String htmlStr = close_page; //define html file in string
ESPserver.send(200, "text/html", htmlStr);
digitalWrite(sleepPin, HIGH); //enables motor driver, turns off sleep mode digitalWrite(dirPin, LOW);
analogWrite(stepPin, 127); //set PWM to 80% duty cycle for now Serial.println("Close signal sent.");
delay(2200);
analogWrite(stepPin,0);
digitalWrite(sleepPin,LOW);
}

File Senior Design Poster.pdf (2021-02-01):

# Smart Window Blinds

# Aya Mistica & Rui Chen University of Wyoming College of Engineering and Applied Science Electrical and Computer Engineering

This project aims to create and design an independent IoT system allowing users to open and close their household vertical blinds with just a simple tap on their personal mobile phones or tablets. The project requires three parts involving the software, hardware, and mechanical developments. The software aspect involves a web application which allows the user to open or close the blinds as they wish. The web application communicates to the hardware unit via WiFi where the user data is received by the System On Chip (SOC), ESP8266. The ESP8266 can then send out PWM signals to the stepper motor which along with the mechanical design is able to physically move the window blinds. The web application is implemented using HTML and CSS styling uploaded to the ESP8266 web server. The ESP8266 is programmed using the Arduino IDE, and the mechanical design independently sketched and designed using Tinkercad.

ESP8266-01
Microcontroller
Unit

NEMA 17 (13 N-cm)
Stepper Motor

9V Battery

3,3V Regulator
(LD1117AV33)

Mini Vertical
Blinds
For testing
(24in by 24in)

DRV8834
Motor Carrier
Driver

USB to TTL Adapter

Rocker LED Switch

5V Regulator
(L7805ACD2T-TR)

Tablet or Mobile
Device with
Internet
Access

## Twist Bar

Connects the stepper
motor to the small
rotating fixture on
the blinds
- AutoConnectAP shows up on mobile device’s network list once system is switched on
- Provides user interface to enter WiFi information for ESP8266 to gain internet access
- Once mobile device and ESP8266 is in the same network, IP address of ESP8266 can be entered into the browser to access the smart window blinds web application

## Motor - Blind Attachment

Square block attaches to stepper motor on one side and to
window blinds on the other so that stepper motor can be
mounted on the side of window blinds
Vic Bershinsky | Ben Heesen
Dr. Steven Barrett | Gale Bandsma
Dr. Robert Kubichek | UW Information Technology

Packaging design includes a battery case for 9V battery, a round rocker switch on the side so system can be turned on/off and enough space for PCB board to be mounted.

The schematic above was tested on a breadboard as shown with a 9V power supply. Initially, we tested each part of the project separately, starting with the web application.
1. AutoConnectAP connects the ESP8266 to the network, the IP address is obtained to access the web application, then either the “LEFT” or “RIGHT” button was pressed. After pressing a button on the web application, we wrote out print statements for the serial monitor so we know that control signals are being transmitted from the output pins.
2. Connected circuit to oscilloscope to confirm that control signals were being sent to the input pins of the motor driver (STEP, DIR, and SLP).
3. Tested the entire system with stepper motor and rewired the motor driver as well as the stepper motor multiple times to get fluid rotations.
4. Adjusted the delay in the code so that the window blinds do not over-rotate.

# Web Application

# Testing and Results

Abstract | Schematic and PCB Layout

# Materials

# Packaging

# Mechanical Designs Acknowledgements

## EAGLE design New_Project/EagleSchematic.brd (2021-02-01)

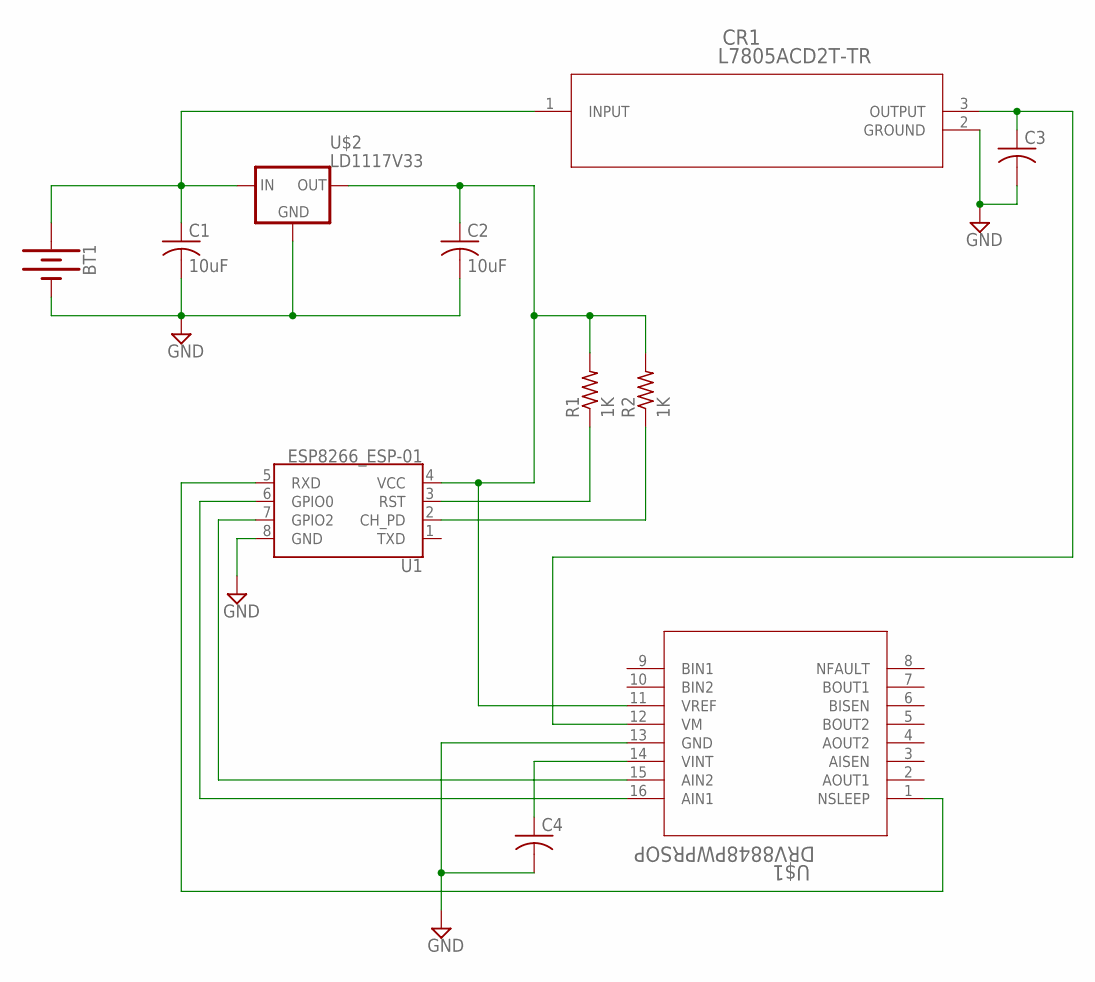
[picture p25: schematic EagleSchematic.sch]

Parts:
BT1: BATTERY-9V; BATTCON_9V
C1, C2: 10uF; C025-024X044
C3, C4: C-US025-024X044; C025-024X044
CR1: L7805ACD2T-TR; D2PAK
R1, R2: 1K; 0204/5
U1: ESP8266_ESP-01
U$1: DRV8848PWPRSOP; SOIC127P1032X265-16
U$2: LD1117V33

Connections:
3.3V: C2.1, R1.2, R2.2, U1.4 (VCC), U$1.11 (VREF), U$2.OUT
GND: C3.2, C4.2, CR1.2 (GROUND), U1.8 (GND), U$1.13 (GND)
unnamed: BT1.+, C1.1, CR1.1 (INPUT), U$2.IN
unnamed: BT1.-, C1.2, C2.2, U$2.GND
unnamed: C4.1, U$1.14 (VINT)
unnamed: R1.1, U1.3 (RST)
unnamed: R2.1, U1.2 (CH_PD)
unnamed: C3.1, CR1.3 (OUTPUT), U$1.12 (VM)
unnamed: U1.7 (GPIO2), U$1.15 (AIN2)
unnamed: U1.6 (GPIO0), U$1.16 (AIN1)
unnamed: U1.5 (RXD), U$1.1 (NSLEEP)

Board: 2 copper layers, 11 parts (0 on the bottom side), 11 nets, no tracks yet.

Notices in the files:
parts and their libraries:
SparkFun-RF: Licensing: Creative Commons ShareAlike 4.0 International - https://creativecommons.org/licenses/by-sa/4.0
